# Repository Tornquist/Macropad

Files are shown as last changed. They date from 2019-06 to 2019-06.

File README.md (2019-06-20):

# Macropad

A 12-key 4x3 macropad for Cherry MX Switches designed in Eagle and
configured with QMK.

* [PCB](PCB/)
* [Bill of Materials](BOM.md)
* [Firmware](Firmware/)

## Assembled Board

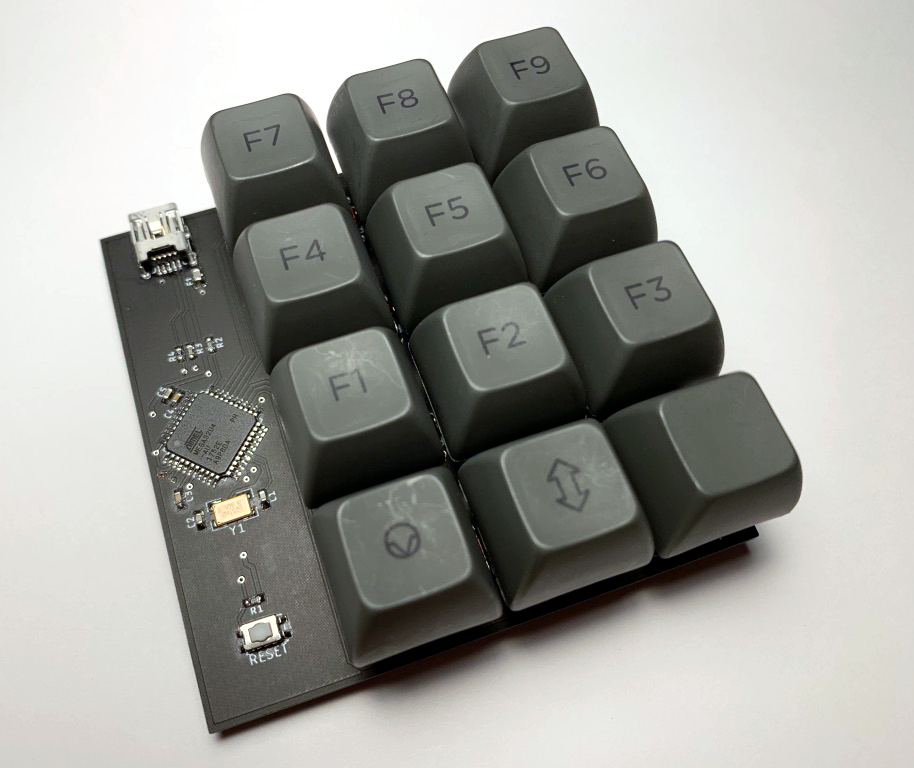
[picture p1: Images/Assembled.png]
Assembled


## Keymap

| Base | Raised |
|:---:|:---:|
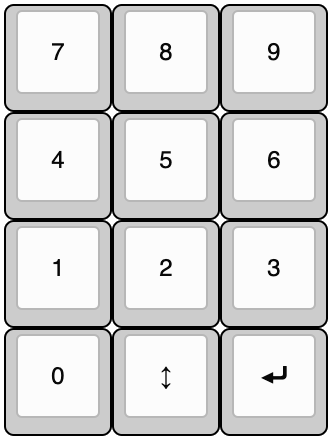
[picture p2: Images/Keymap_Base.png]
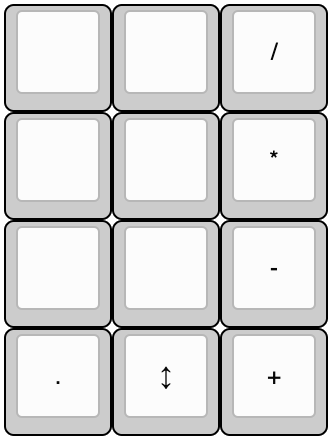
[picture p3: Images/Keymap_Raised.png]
|  |  |

## PCB

| Top | Bottom |
|:---:|:---:|
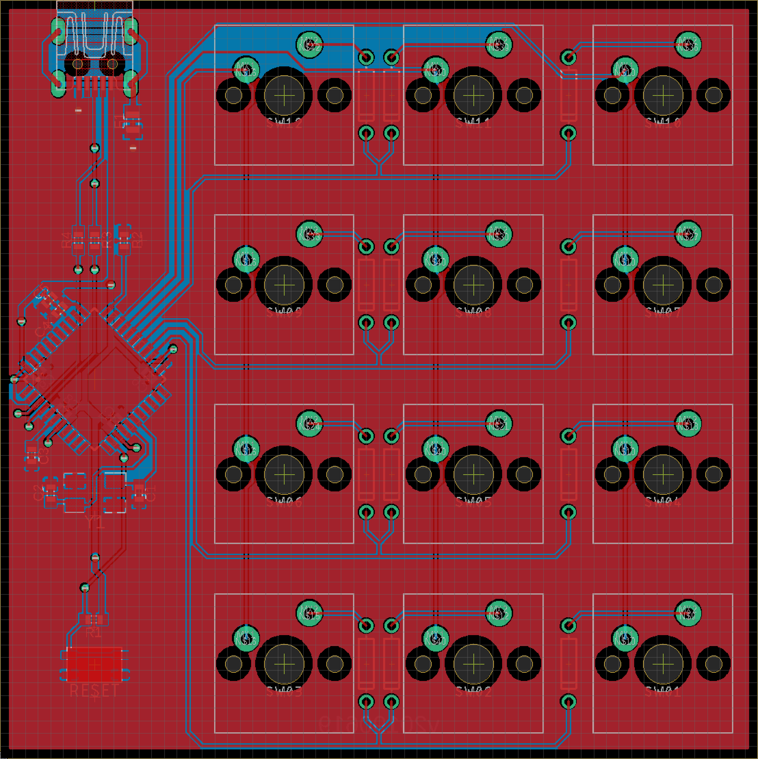
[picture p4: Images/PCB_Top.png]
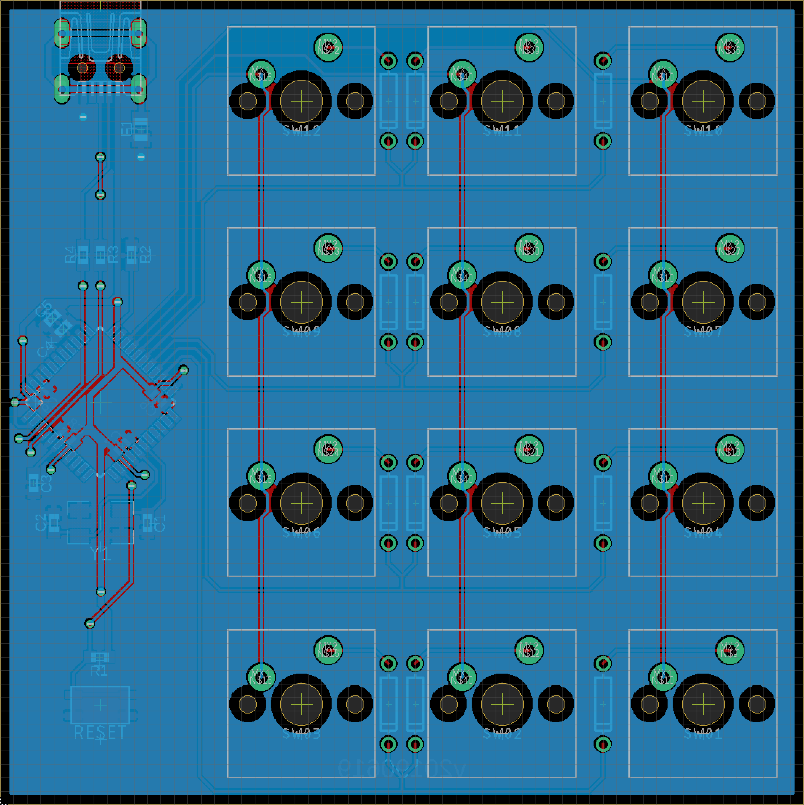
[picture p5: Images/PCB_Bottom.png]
|  |  |

## Schematic

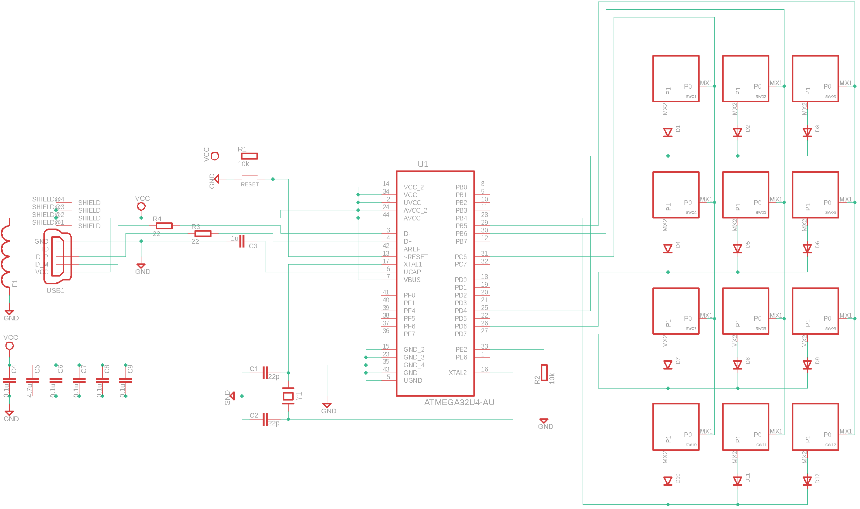
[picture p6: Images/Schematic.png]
Schematic


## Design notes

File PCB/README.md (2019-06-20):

# PCB

This board was designed in Eagle and relies on a collection of different
component libraries.

* [ATMEGA32U4-AU](https://www.snapeda.com/parts/ATMEGA32U4-AU/Microchip/view-part/)
* [Clueboard Libraries](https://github.com/clueboard/eagle_libs)
* [Adafruit Library](https://github.com/adafruit/Adafruit-Eagle-Library)
* supply2

## Revisions

### v20190619
* Corrected mismatched D+ and D- connections

### v20190608
* ATMEGA packaging changed from QFN to TQFP
* Crystal packaging changed from 3.2x2.5 to 3.2x5
* Replaced metric 0603 diodes with through-hole 1N4148
* Rerouted board to accommodate and balance component changes

### v20190525
* Initial Layout

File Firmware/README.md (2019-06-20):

# Firmware

This keyboard is configured using [QMK](https://github.com/qmk).

To flash or modify the firmware:

1. Connect the fresh board to a computer and verify it is available
   as a USB device. A fresh atmega will show up with a name similar
   to `Atmel Corporation ATm32U4DFU Serial: 1.0.0`
   * If the device is not recognized, verify and test all of the
     connections on the board. This chip comes pre-flashed with
     the atmel bootloader and should be recognized.
1. Install [QMK Toolbox](https://github.com/qmk/qmk_toolbox)

	> Note: The installation steps in the README dependency list were
	> insufficient for me. I had to follow the more explicit list in the
	> documentation, where `avr-gcc` is explicitly `avr-gcc@8`

2. Download [QMK Firmware](https://github.com/qmk/qmk_firmware)
3. Copy the contents of this folder into `keyboards/macropad` in the
   downloaded QMK Firware directory
4. Run `make macropad:default` to build the `*.hex` file
5. Select the `*.hex` in `QMK Toolbox`
6. Press the reset button on the board
7. Click flash from `QMK Toolbox`. The logs should show the board being
   flashed and reconnecting as a named keyboard.

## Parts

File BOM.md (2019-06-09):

# Bill of Materials

| Item | Package | Mouser Product ID | Quantity | Unit Price | Total Price |
|:---|:---|:---|---:|---:|---:|
| Cherry MX Switch | Through Hole | [540-MX1A-E1NW][1] | 12 | $0.840 | $10.080 |
| 1N4148 Diode | Through Hole | [512-1N4148][2] | 12 | $0.174 | $2.088 |
| ATMEGA32U4-AU | TQFP-44 | [556-ATMEGA32U4-AU][3] | 1 | $4.090 | $4.090 |
| 16MHz Crystal | 3.2x5 | [520-160-18-30B-AGNT][4] | 1 | $0.580 | $0.580 |
| 22p Cap | 0603 | [80-C0603C220J5G7411][5] | 2 | $0.104 | $0.208 |
| 4.7u Cap | 0603 | [963-LMK107BJ475MAHT][6] | 1 | $0.110 | $0.110 |
| 1u Cap | 0603 | [963-TMK107BLD105MA-T][7]  | 1 | $0.215 | $0.215 |
| 0.1u Cap | 0603 | [80-C0603C104J4RECLR][8] | 5 | $0.073 | $0.365 |
| 10K Resistor | 0603 | [71-CRCW060310K0FKEAC][9]  | 2 | $0.065 | $0.130 |
| 22 Resistor | 0603 | [71-CRCW060322R0FKEAC][10] | 2 | $0.036 | $0.072 |
| Switch | EVQP2 | [667-EVQ-P2602W][11] | 1 | $0.750 | $0.750 |
| Ferrite Bead | 0805 | [81-BLM21SP471SH1D][12] | 1 | $0.250 | $0.250 |
| USB Mini Female  | | [798-UX60-MB-5S8][13] | 1 | $1.530 | $1.530 |
| | | | | | $19.038 |

[1]: https://www.mouser.com/ProductDetail/540-MX1A-E1NW
[2]: https://www.mouser.com/ProductDetail/512-1N4148
[3]: https://www.mouser.com/ProductDetail/556-ATMEGA32U4-AU
[4]: https://www.mouser.com/ProductDetail/520-160-18-30B-AGNT
[5]: https://www.mouser.com/ProductDetail/80-C0603C220J5G7411
[6]: https://www.mouser.com/ProductDetail/963-LMK107BJ475MAHT
[7]: https://www.mouser.com/ProductDetail/963-TMK107BLD105MA-T
[8]: https://www.mouser.com/ProductDetail/80-C0603C104J4RECLR
[9]: https://www.mouser.com/ProductDetail/71-CRCW060310K0FKEAC
[10]: https://www.mouser.com/ProductDetail/71-CRCW060322R0FKEAC
[11]: https://www.mouser.com/ProductDetail/667-EVQ-P2602W
[12]: https://www.mouser.com/ProductDetail/81-BLM21SP471SH1D
[13]: https://www.mouser.com/ProductDetail/798-UX60-MB-5S8

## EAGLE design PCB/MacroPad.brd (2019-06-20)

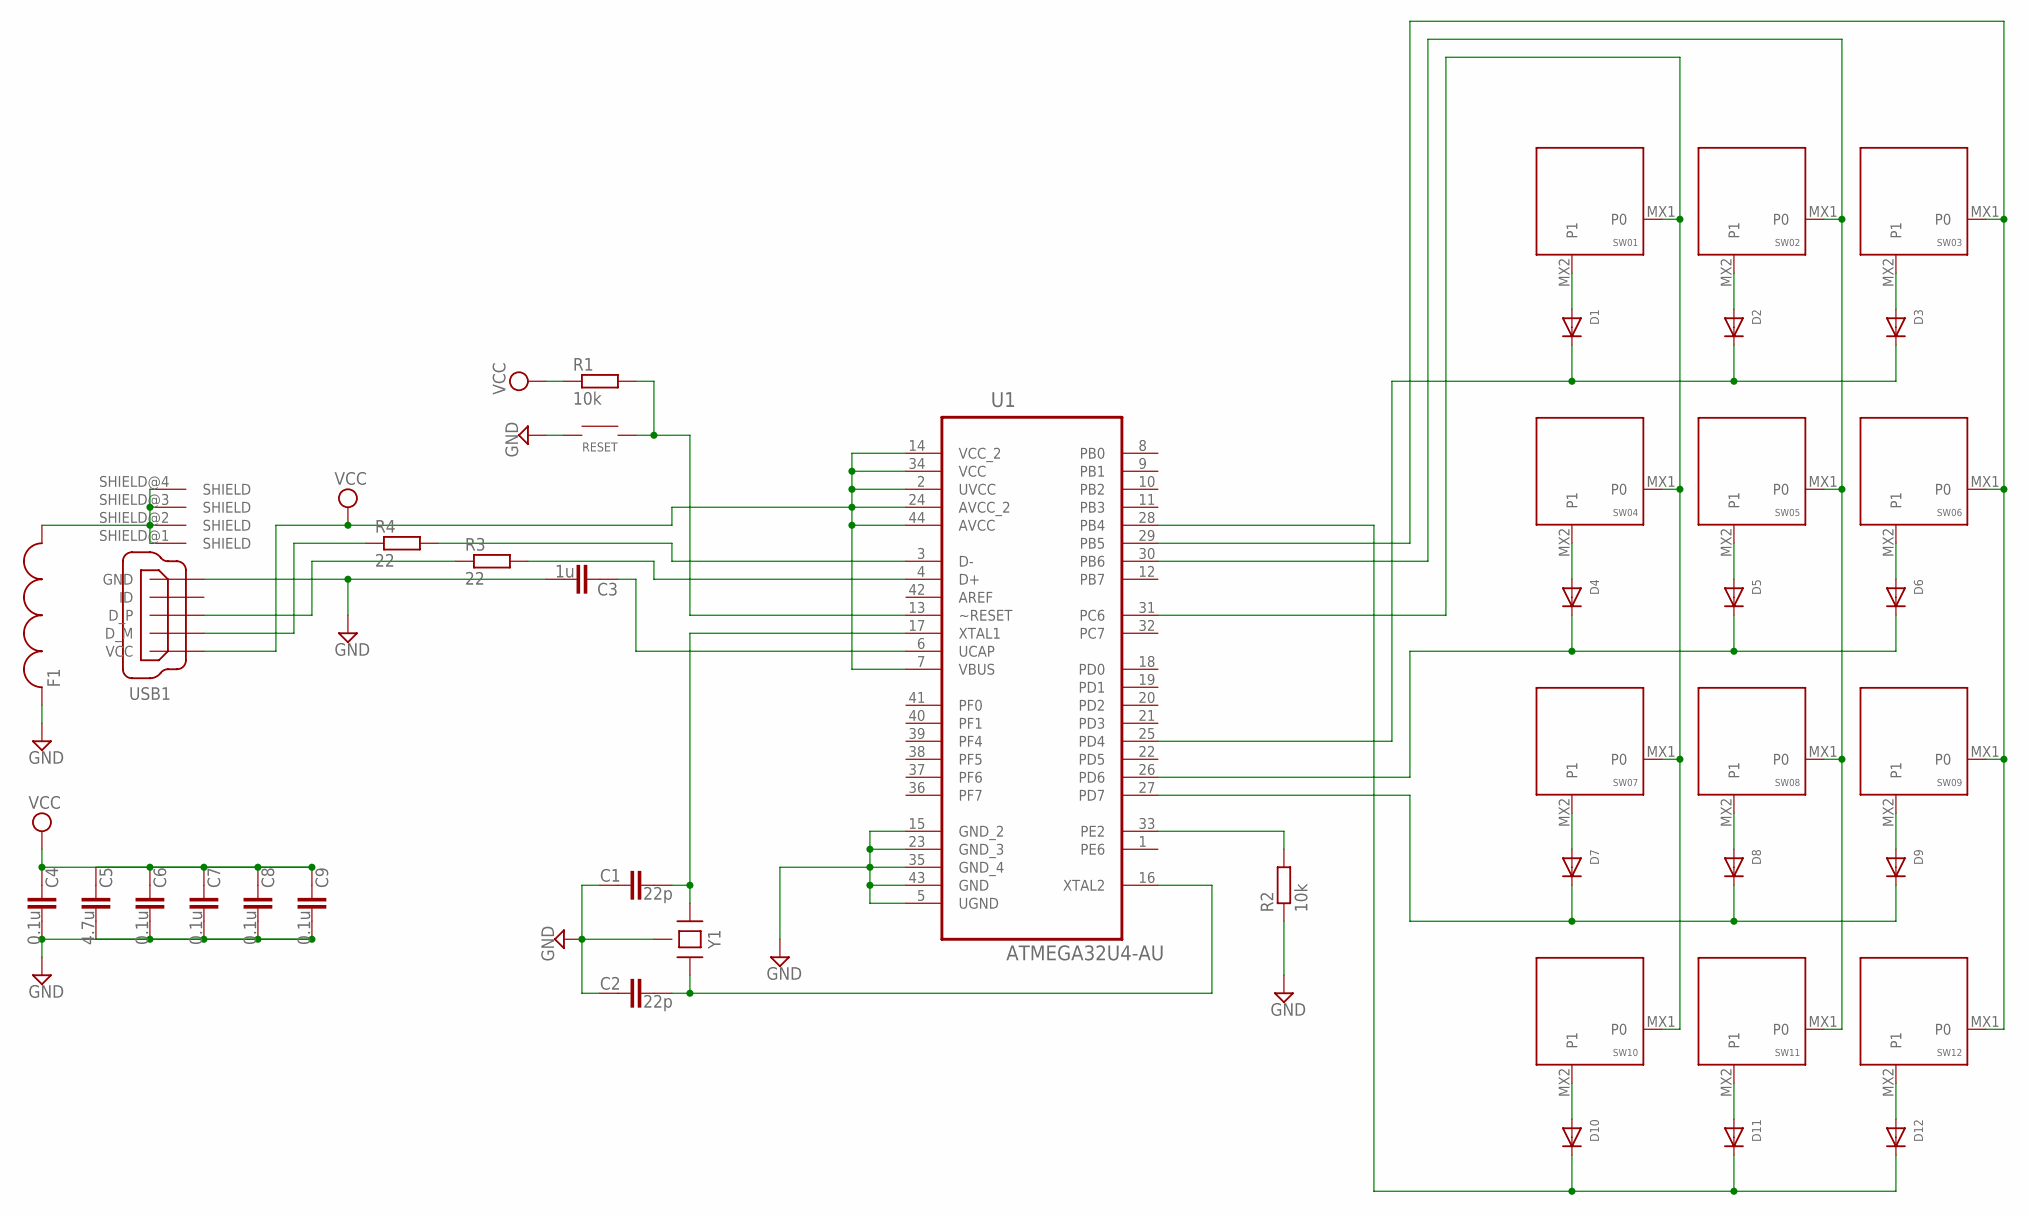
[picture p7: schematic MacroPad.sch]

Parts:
C1, C2: 22p; C0603; MPN 04025A220JAT2A
C3: 1u; C0603
C4, C6, C7, C8, C9: 0.1u; C0603
C5: 4.7u; C0603
D1, D2, D3, D4, D5, D6, D7, D8, D9, D10, D11, D12: DIODEDO-1N4148; DO-1N4148
F1: FERRITE-0805; F0805
R1, R2: 10k; R0603
R3, R4: 22; R0603
RESET: SWITCH-SMD-EVQP-P2602W
SW01, SW02, SW03, SW04, SW05, SW06, SW07, SW08, SW09, SW10, SW11, SW12: KEYSWITCH-PLAIN-MX-1U; MX-1U
U1: ATMEGA32U4-AU; QFP80P1200X1200X120-44N
USB1: USB_CONN-MINI-FEMALE; UX60-MB-5S8
Y1: CRYSTAL-4PIN-3.2X5; CRYSTAL-3.2X5

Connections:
GND: C1.1, C2.1, C3.2, C4.2, C5.2, C6.2, C7.2, C8.2, C9.2, F1.1, R2.1, RESET.1A (1), RESET.1B (1), U1.5 (UGND), U1.15 (GND_2), U1.23 (GND_3), U1.35 (GND_4), U1.43 (GND), USB1.GND, Y1.2 (GND), Y1.4 (GND)
unnamed: C2.2, U1.16 (XTAL2), Y1.3 (2)
unnamed: C1.2, U1.17 (XTAL1), Y1.1
unnamed: R1.2, RESET.2A (2), RESET.2B (2), U1.13 (~RESET)
unnamed: R2.2, U1.33 (PE2)
unnamed: R4.1, USB1.D- (D_M)
unnamed: R4.2, U1.3 (D-)
unnamed: R3.1, USB1.D+ (D_P)
unnamed: R3.2, U1.4 (D+)
unnamed: D1.A, SW01.MX2 (P1)
unnamed: SW01.MX1 (P0), SW04.MX1 (P0), SW07.MX1 (P0), SW10.MX1 (P0), U1.31 (PC6)
unnamed: F1.2, USB1.SHIELD@1 (SHIELD), USB1.SHIELD@2 (SHIELD), USB1.SHIELD@3 (SHIELD), USB1.SHIELD@4 (SHIELD)
unnamed: D2.A, SW02.MX2 (P1)
unnamed: D1.C, D2.C, D3.C, U1.25 (PD4)
unnamed: D3.A, SW03.MX2 (P1)
unnamed: SW03.MX1 (P0), SW06.MX1 (P0), SW09.MX1 (P0), SW12.MX1 (P0), U1.29 (PB5)
unnamed: D4.A, SW04.MX2 (P1)
unnamed: D5.A, SW05.MX2 (P1)
unnamed: D6.A, SW06.MX2 (P1)
unnamed: D4.C, D5.C, D6.C, U1.26 (PD6)
unnamed: D7.A, SW07.MX2 (P1)
unnamed: D8.A, SW08.MX2 (P1)
unnamed: D7.C, D8.C, D9.C, U1.27 (PD7)
unnamed: D9.A, SW09.MX2 (P1)
unnamed: D10.A, SW10.MX2 (P1)
unnamed: D10.C, D11.C, D12.C, U1.28 (PB4)
unnamed: D11.A, SW11.MX2 (P1)
unnamed: SW02.MX1 (P0), SW05.MX1 (P0), SW08.MX1 (P0), SW11.MX1 (P0), U1.30 (PB6)
unnamed: D12.A, SW12.MX2 (P1)
UCAP: C3.1, U1.6 (UCAP)
VCC: C4.1, C5.1, C6.1, C7.1, C8.1, C9.1, R1.1, U1.2 (UVCC), U1.7 (VBUS), U1.14 (VCC_2), U1.24 (AVCC_2), U1.34 (VCC), U1.44 (AVCC), USB1.VCC

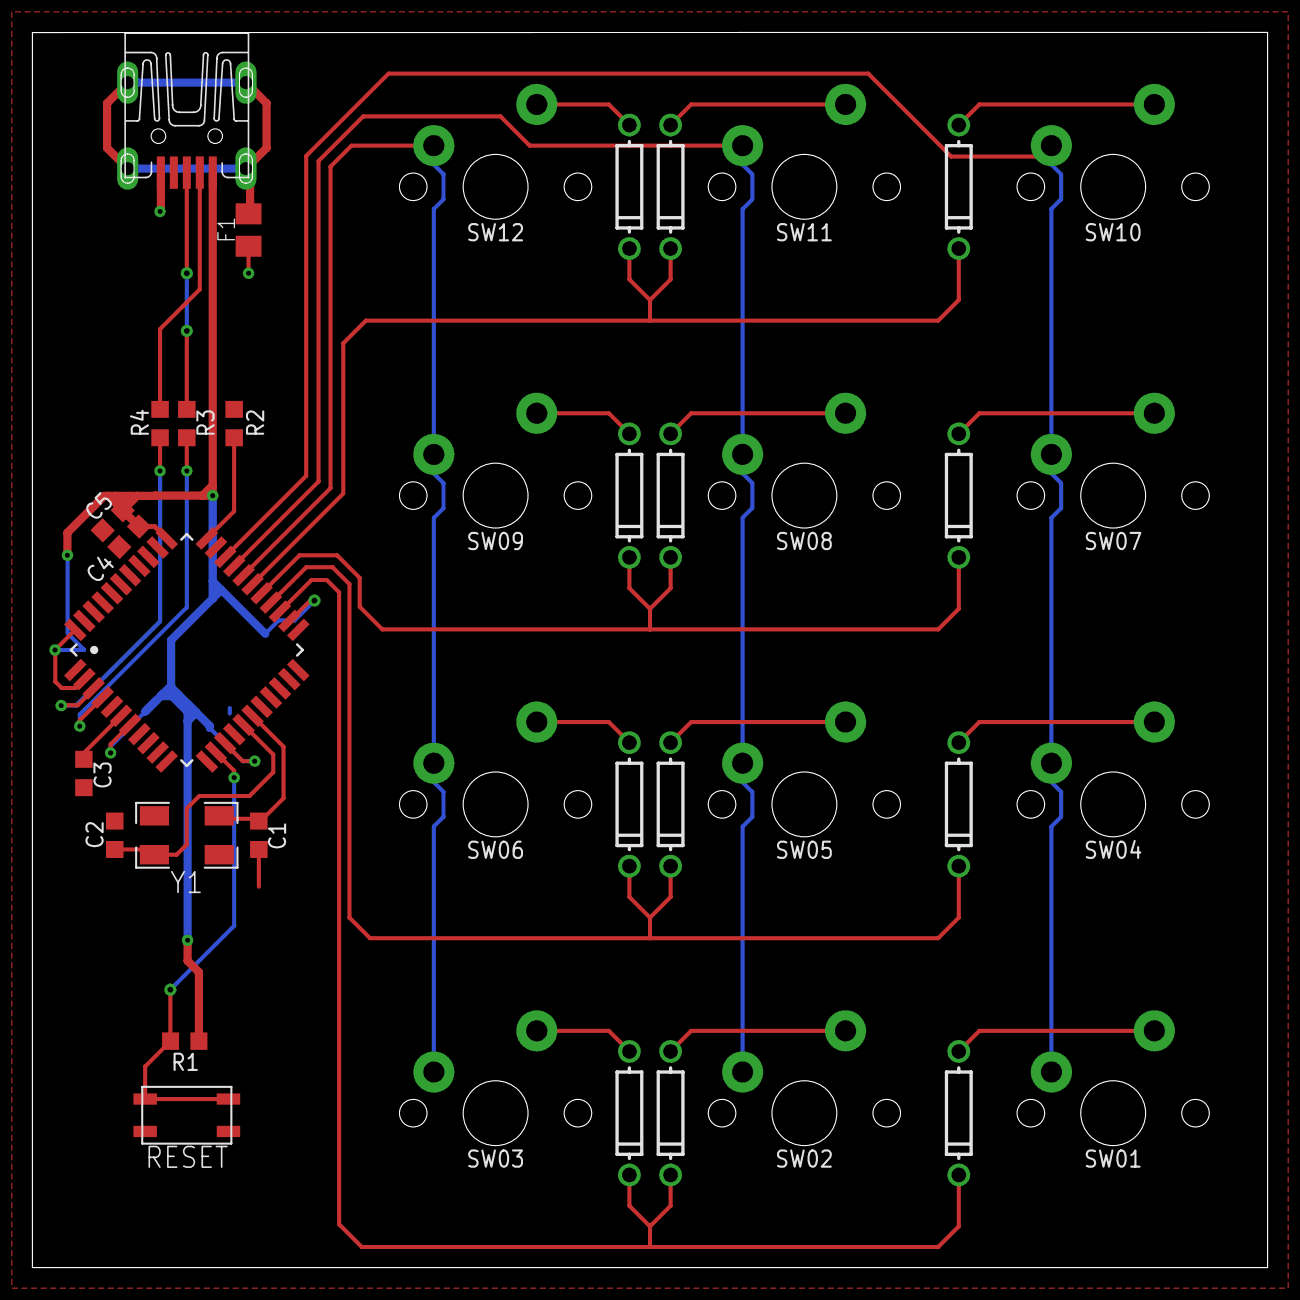
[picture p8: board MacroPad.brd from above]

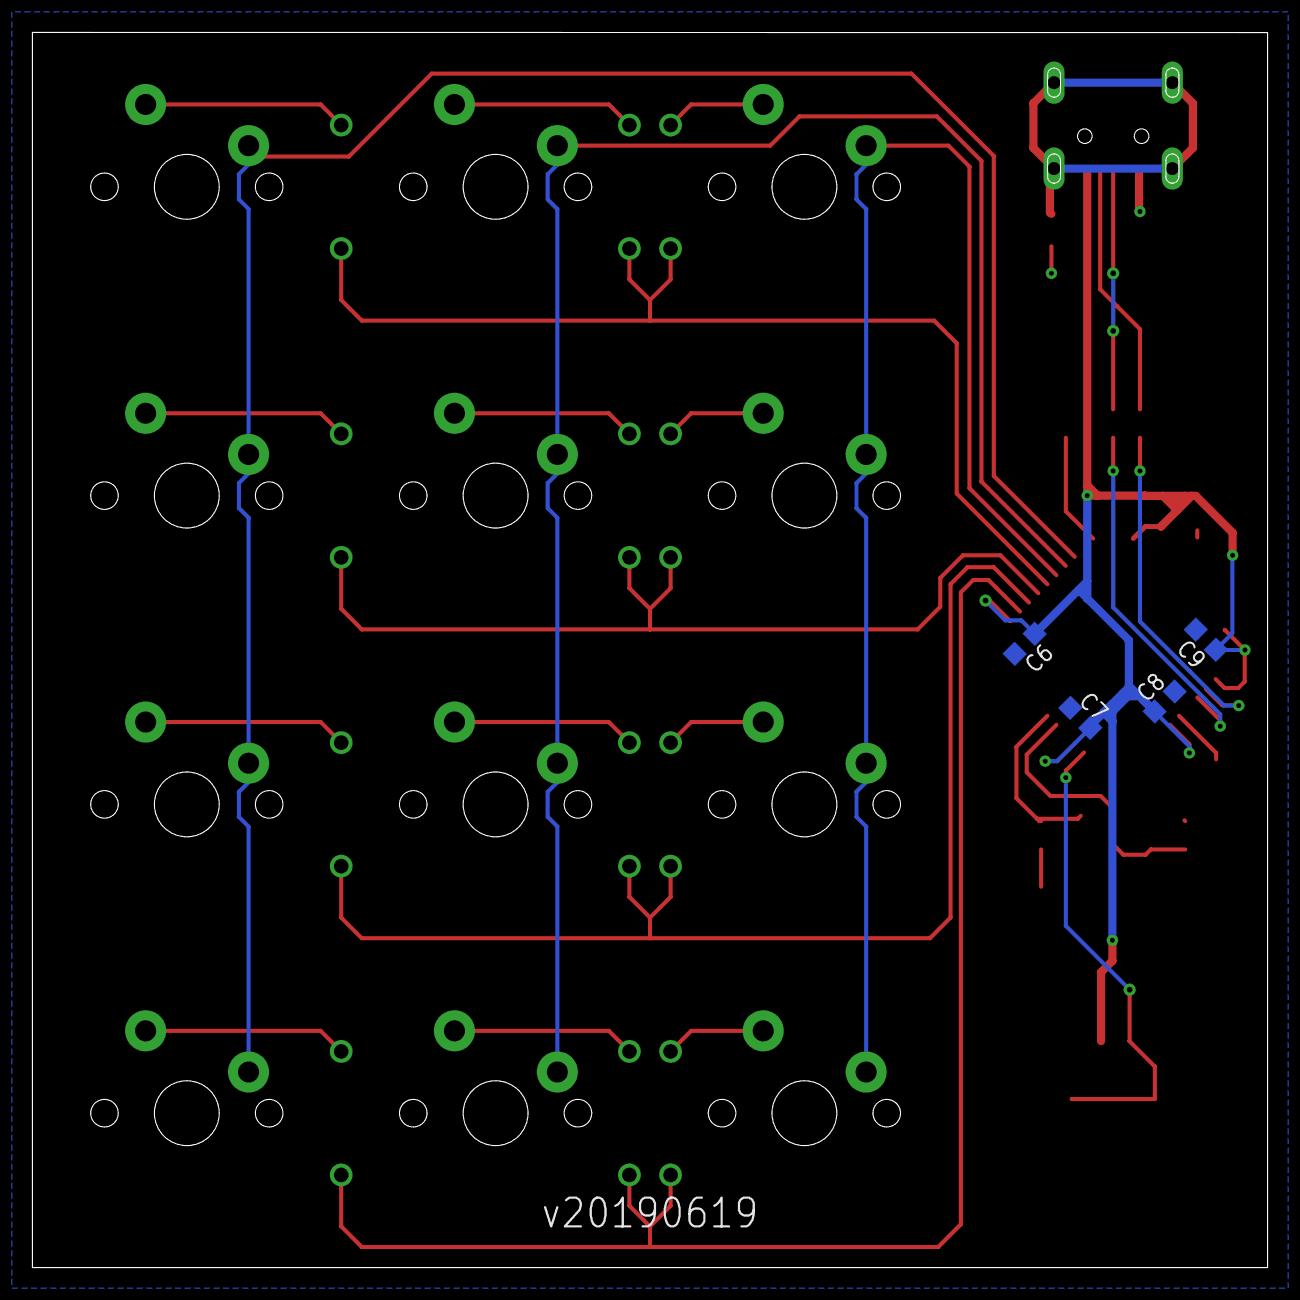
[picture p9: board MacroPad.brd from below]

Board: 2 copper layers, 76.2 x 76.2 mm, 42 parts (4 on the bottom side), 31 nets.

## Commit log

2019-05-17 Connect processor to usb and power
    [MacroPad.sch]
2019-05-17 Add switch array and connect to microcontroller
    [MacroPad.sch]
2019-05-17 Rough board estimation: checking size
    [MacroPad.brd]
2019-05-18 Move Eagle into /Eagle and add KiCad/* schematic
    [MacroPad.brd, MacroPad.kicad_pcb, MacroPad.sch]
2019-05-18 Keyboard schematic with associated parts
    [MacroPad.sch]
2019-05-18 Arrange components for size analysis with accurate mx switches
    [MacroPad.kicad_pcb, MacroPad.sch]
2019-05-21 Redo schematic in Eagle using clueboard library
    [MacroPad.sch]
2019-05-21 Create schematic and start aligning pin order
    [MacroPad.brd, MacroPad.sch]
2019-05-21 Update switch and chip footprints, and switch array pins
    [MacroPad.brd, MacroPad.sch]
2019-05-21 Route rows
    [MacroPad.brd]
2019-05-21 Route columns
    [MacroPad.brd]
2019-05-21 Routed board
    [MacroPad.brd, MacroPad.sch]
2019-05-22 Compress row traces
    [MacroPad.brd]
2019-05-22 Components routed in compressed area
    [MacroPad.brd, MacroPad.sch]
2019-05-22 Shrink board
    [MacroPad.brd, MacroPad.sch]
2019-05-23 Redone schematic with smaller capacitors, fixed decoupling capacitors, and adjusted trace sizes
    [MacroPad.brd, MacroPad.sch]
2019-05-23 Add top and bottom ground plane and merge gnd and ugnd
    [MacroPad.brd, MacroPad.sch]
2019-05-23 Reduce acute angles and move vias farther from board
    [MacroPad.brd]
2019-05-23 Align all labels
    [MacroPad.brd]
2019-05-25 Update layout with appropriate spacing between switches (100mil border)
    [MacroPad.brd, MacroPad.sch]
2019-05-25 Adjust vias position based on JLCPCB rendering
    [MacroPad.brd]
2019-05-25 Add version number to board
    [MacroPad.brd]
2019-05-25 Add Bill of Materials and README
    [MacroPad.brd, MacroPad.sch]
2019-05-25 Remove working schematics and move v20190525 to PCB/
    [MacroPad.brd, MacroPad.kicad_pcb, MacroPad.sch]
2019-06-08 Replace surface mount diodes with through hole
    [MacroPad.brd, MacroPad.sch]
2019-06-08 Swap GFN for TQFP Chip -- board not updated
    [MacroPad.brd, MacroPad.sch]
2019-06-08 Update board for TQFP footprint
    [MacroPad.brd]
2019-06-08 Use 5x3.2mm crystal
    [MacroPad.brd, MacroPad.sch]
2019-06-08 Reroute columns to avoid vias
    [MacroPad.brd, MacroPad.sch]
2019-06-08 Rename components based on board position
    [MacroPad.brd, MacroPad.sch]
2019-06-08 Add label for chip orientation
    [MacroPad.brd]
2019-06-09 Finishing Touches: Date, cam file, row 2 routing, chip orientation indicator
    [MacroPad.brd]
2019-06-09 Use ATMEGA32U4-AU
    [MacroPad.brd, MacroPad.sch]
2019-06-20 Update PCB to correct D- and D+ mapping. Increment Date
    [MacroPad.brd, MacroPad.sch]
2019-06-20 Added PCB Readme with eagle references
2019-06-20 Add schematic
2019-06-20 Add top and bottom pcb images
2019-06-20 Add assembled image and keymaps
